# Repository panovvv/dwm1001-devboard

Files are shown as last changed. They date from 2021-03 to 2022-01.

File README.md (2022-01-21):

# DWM1001 Development board
Breakout board for DWM1001 UWB module.

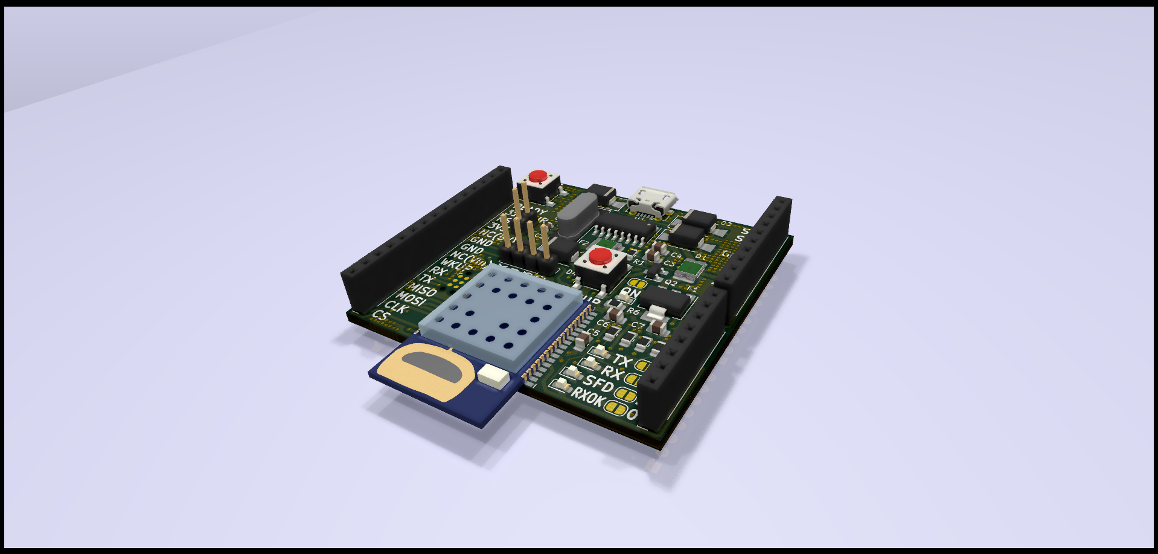
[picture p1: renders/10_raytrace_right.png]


[> Demo video here <](https://www.youtube.com/watch?v=SorOhWdywFg)

Intended for easy exploration:
* Modular thanks to compatibility with Arduino Uno shield footprint.
* Modules can be battery-powered using a simple DIY battery shield.
* Open access to all GPIOs.

## Files and folders:

* `dwm1001-devboard.***`- KiCAD schematics and PCB files.
* `schematic.pdf` - full schematic sheet rendered in PDF.
* `bom.csv` - Bill of Materials, semicolon-separated.
* `paper_footprint_test.pdf` - this is my usual practice when designing and ordering PCBs:
before even designing the board layout, I plot the empty board with all footprints in it to PDF
(1:1 scale), print it on a sheet of paper and do a "test fit" for every component. This helps 
to find footprint inconsistencies early on.
* `gerber/` - Generated according to
[this document](https://support.jlcpcb.com/article/102-kicad-515---generating-gerber-and-drill-files).
To order the PCB made, just zip up all files in `gerber/` folder and send to fab.
* `renders/` - 3D renders and STL of the board with all components populated.
* `SMD_Polyfuse_1812.stp` - model for PTC fuse in 1812 package, courtesy of 
  [Joan The Spark](https://forum.kicad.info/u/Joan_Sparky) distributed under GNU General Public License v2.0. 
  Source: [Kicad forum](https://forum.kicad.info/t/polyfuse-3d-models/6859), [direct link](https://kicad-info.s3-us-west-2.amazonaws.com/original/2X/6/6d10c55baa8ffbd4a3f9c269ba751e2fab07bd70.stp)

## BOM

|Designator|Package |Quantity|Value |
|---|---|---|---|
|F2,F1 |1812 (4532 Metric) |2 |0.5A PTC fuse |
|C2,C1 |0603 (1608 Metric) |2 |22pF ceramic capacitor |
|Y1 |HC49-SD SMD |1 |12MHz crystal oscillator |
|U1 |SOIC-16 |1 |CH340G |
|J1 |Micro USB Type B, SMD |1 |Micro USB B connector, female |
|SW1, SW2  |SPST Pushbutton 6x6mm, SMD |2 |WKUP, RST buttons |
|U3 |SOT-223-3 |1 |AMS1117-3.3 3.3V voltage regulator |
|U2 |DecaWave DWM1001 |1 |DWM1001 |
|R1 |0805 (2012 Metric) |1 |100kΩ resistor |
|Q2,Q1 |SuperSOT-3 |2 |FDN430P P-MOSFET |
|JP1 |2.54mm pitch Male Pin Header 1x02 Vertical  |1 |3.3V Current probe jumper |
|J7 |2.54mm pitch Female Pin Header 1x10 Vertical|1 |Arduino Stackable type if possible |
|J6 |2.54mm pitch Female Pin Header 1x08 Vertical|1 |Arduino Stackable type if possible |
|J4 |2.54mm pitch Female Pin Header 1x15 Vertical|1 |Arduino Stackable type if possible |
|J5 |Tag-Connect TC2030-IDC |1 |Tag-Connect TC2030 SWD |
|J2 |2.54mm pitch Male Pin Header 1x04 Vertical  |1 |SWD Pin Header Male |
|D4 |SMA or SMB Diode |1 |SMBJ3.3A Transient voltage suppressor|
|D1 - D3 |SMA or SMB Diode |3 |SMBJ5.0A Transient voltage suppressor|
|C5,C3 |0805 (2012 Metric) |2 |100nF ceramic capacitor |
|C7,C6,C4  |0805 (2012 Metric) |3 |10µF ceramic capacitor |
|D9 |0603 (1608 Metric) |1 |Green LED |
|D8,D6 |0603 (1608 Metric) |2 |Red LED |
|D7,D5 |0603 (1608 Metric) |2 |Blue LED |
|R6 |0805 (2012 Metric) |1 |47Ω resistor, for green LED @ 3.3V |
|R5,R3 |0805 (2012 Metric) |2 |75Ω resistor, for red LED @ 3.3V |
|R4,R2 |0805 (2012 Metric) |2 |15Ω resistor, for blue LED @ 3.3V |

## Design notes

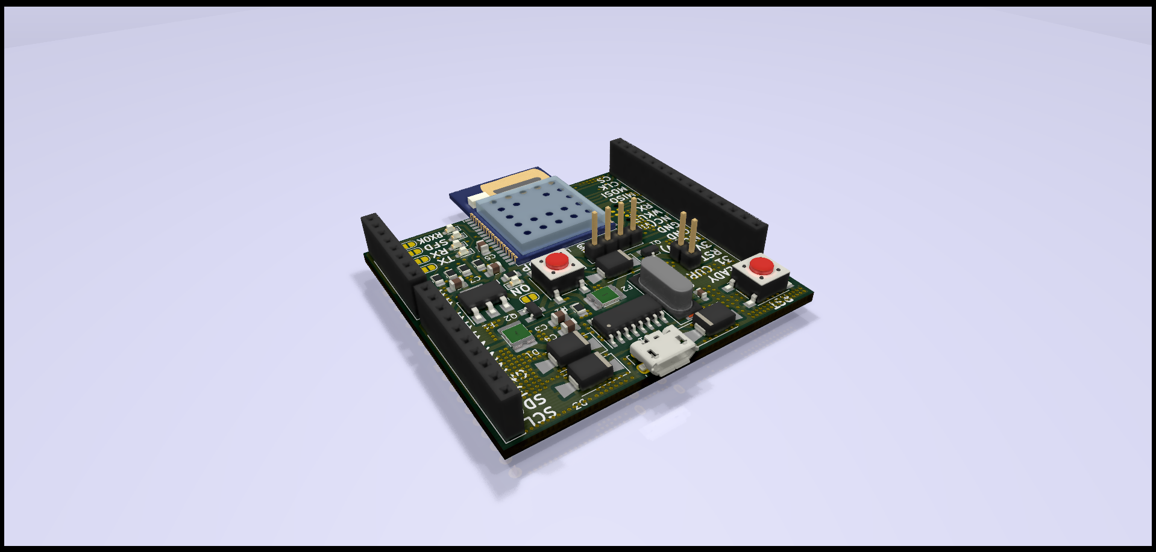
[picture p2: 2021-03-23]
renders/12_raytrace_right_180deg.png

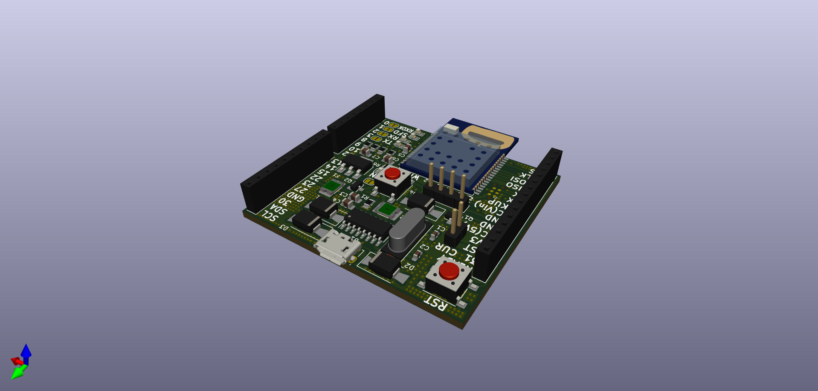
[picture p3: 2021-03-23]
renders/05_no_raytrace_left_180deg.png

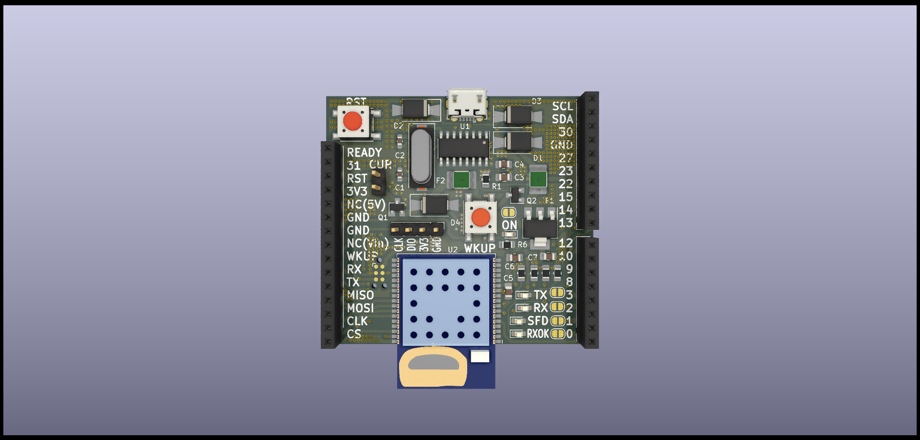
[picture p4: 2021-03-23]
renders/07_raytrace_front.png

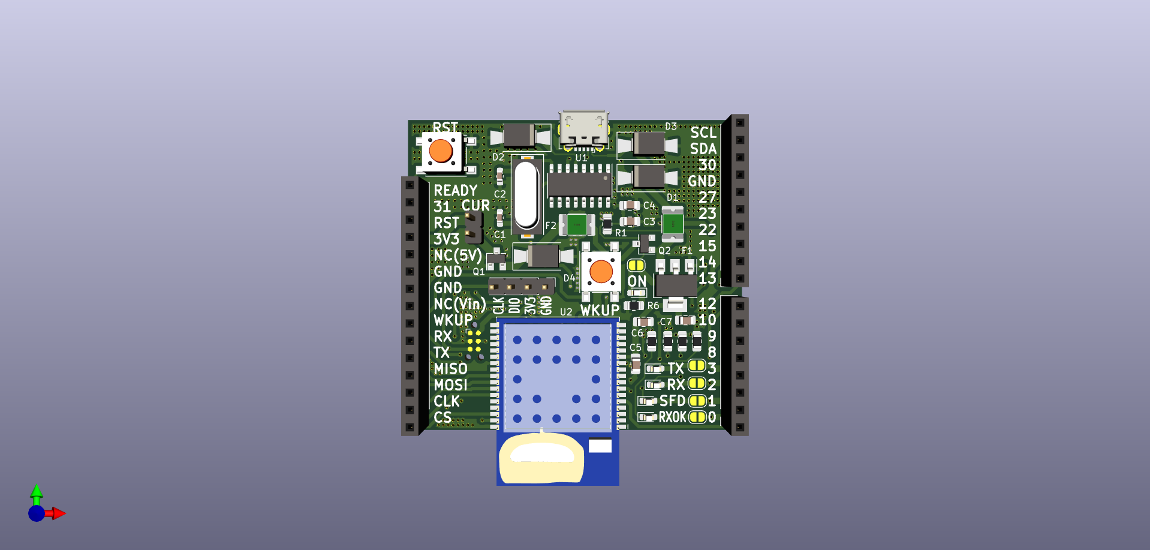
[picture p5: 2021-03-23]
renders/01_no_raytrace_front.png

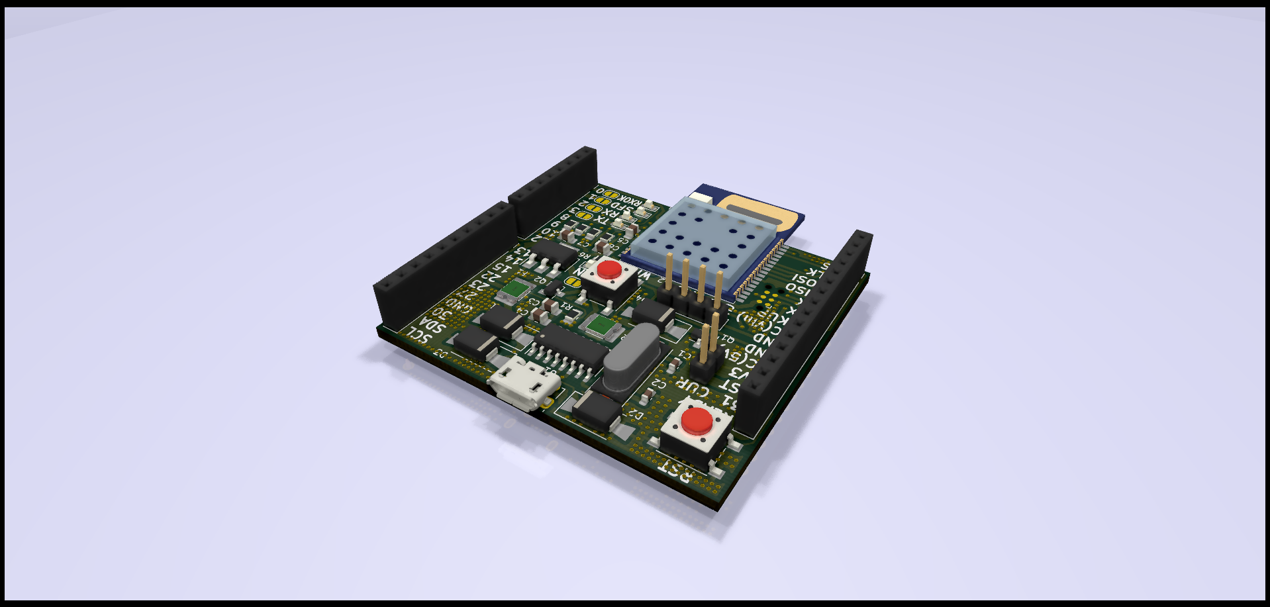
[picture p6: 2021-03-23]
renders/11_raytrace_left_180deg.png

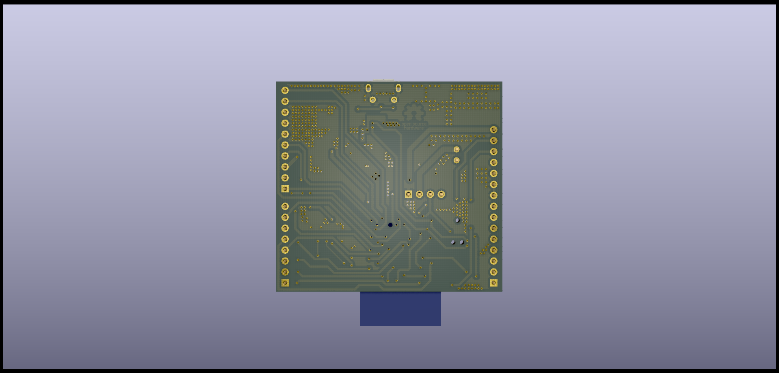
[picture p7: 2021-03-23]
renders/08_raytrace_back.png

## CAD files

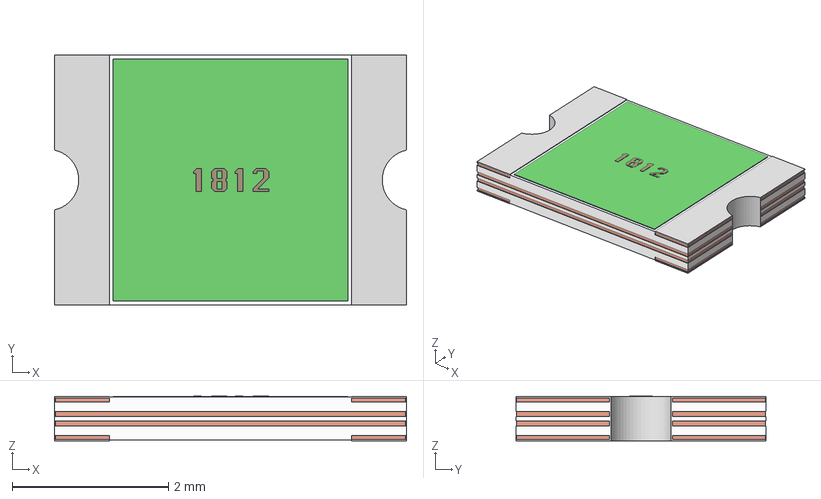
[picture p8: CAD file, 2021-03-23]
SMD_Polyfuse_1812.stp
4.50 x 3.20 x 0.575 mm

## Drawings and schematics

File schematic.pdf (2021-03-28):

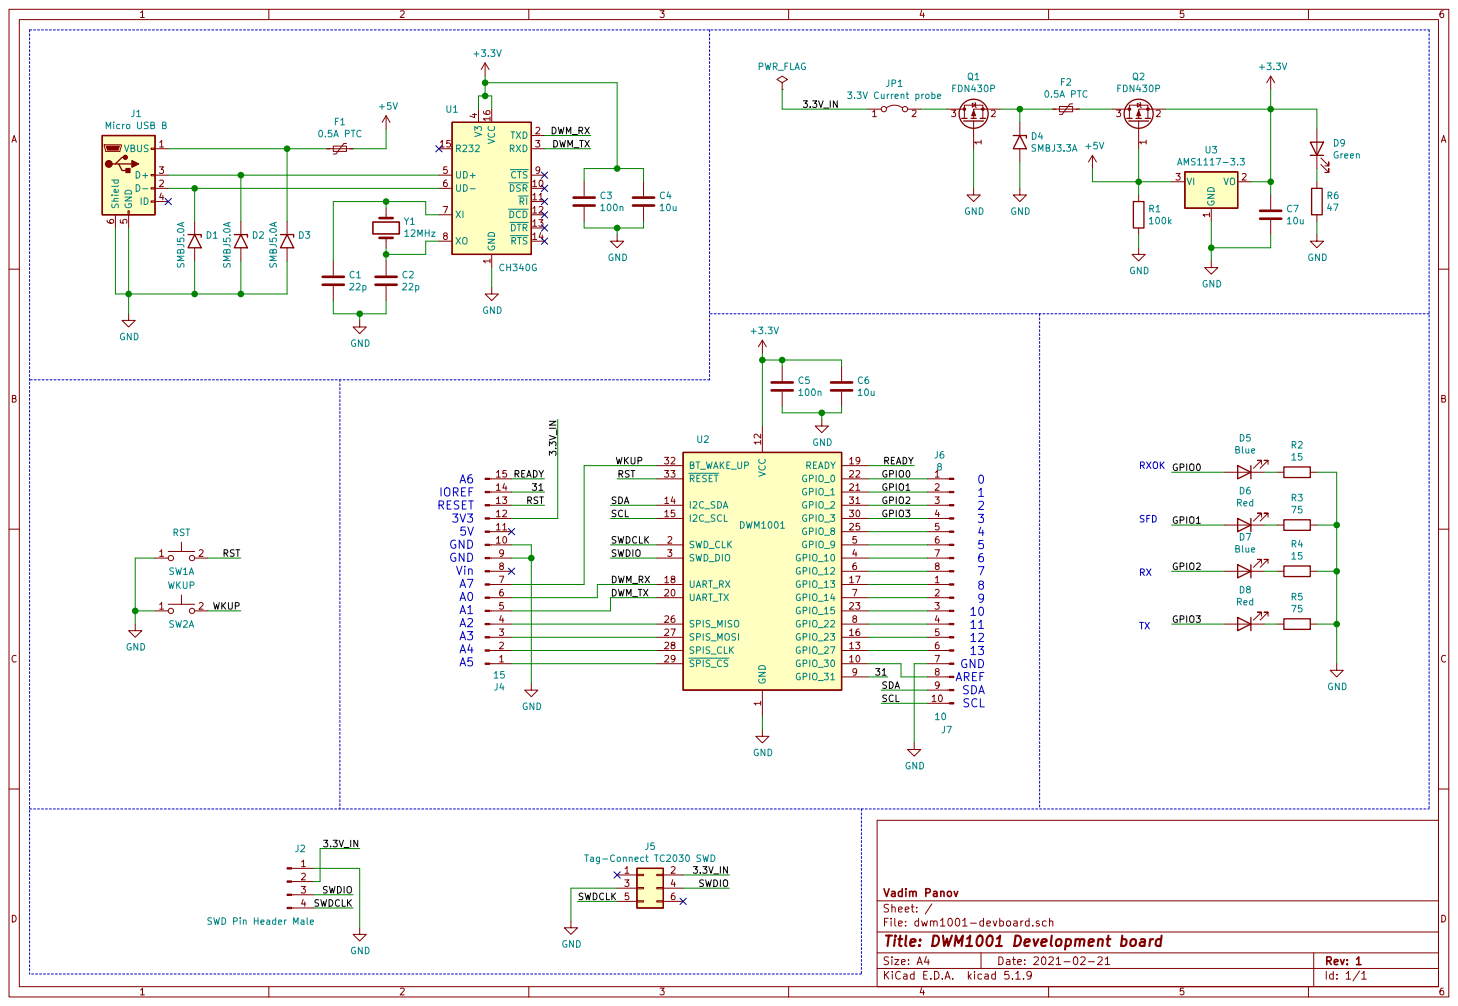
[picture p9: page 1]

4 UD+ 5 UD- 6 XI 7 XO 8 CTS 9 U1 CH340G GND

1 DSR 10 RI 11 DCD 12 DTR 13 RTS 14 R232 15 VCC 16 TXD 2 RXD 3 V3

File: dwm1001-devboard.sch Sheet: / Vadim Panov GND

J2 SWD Pin Header Male

Id: 1/1 Title: DWM1001 Development board

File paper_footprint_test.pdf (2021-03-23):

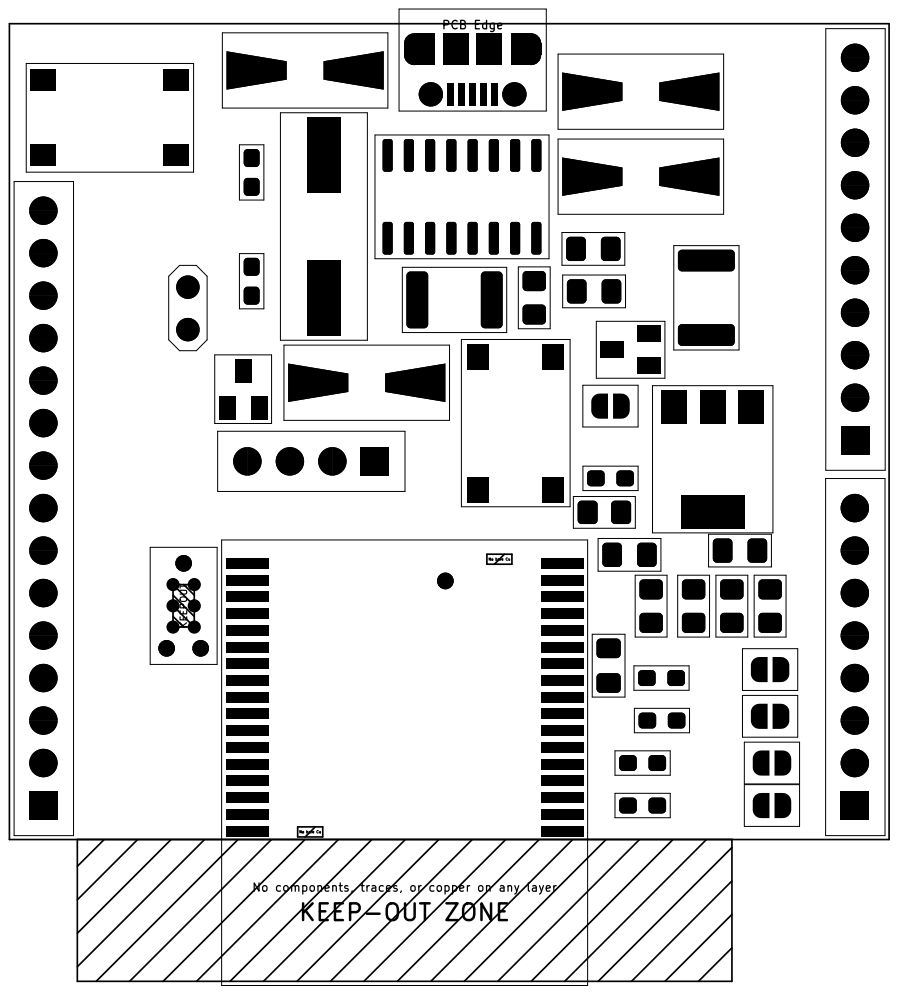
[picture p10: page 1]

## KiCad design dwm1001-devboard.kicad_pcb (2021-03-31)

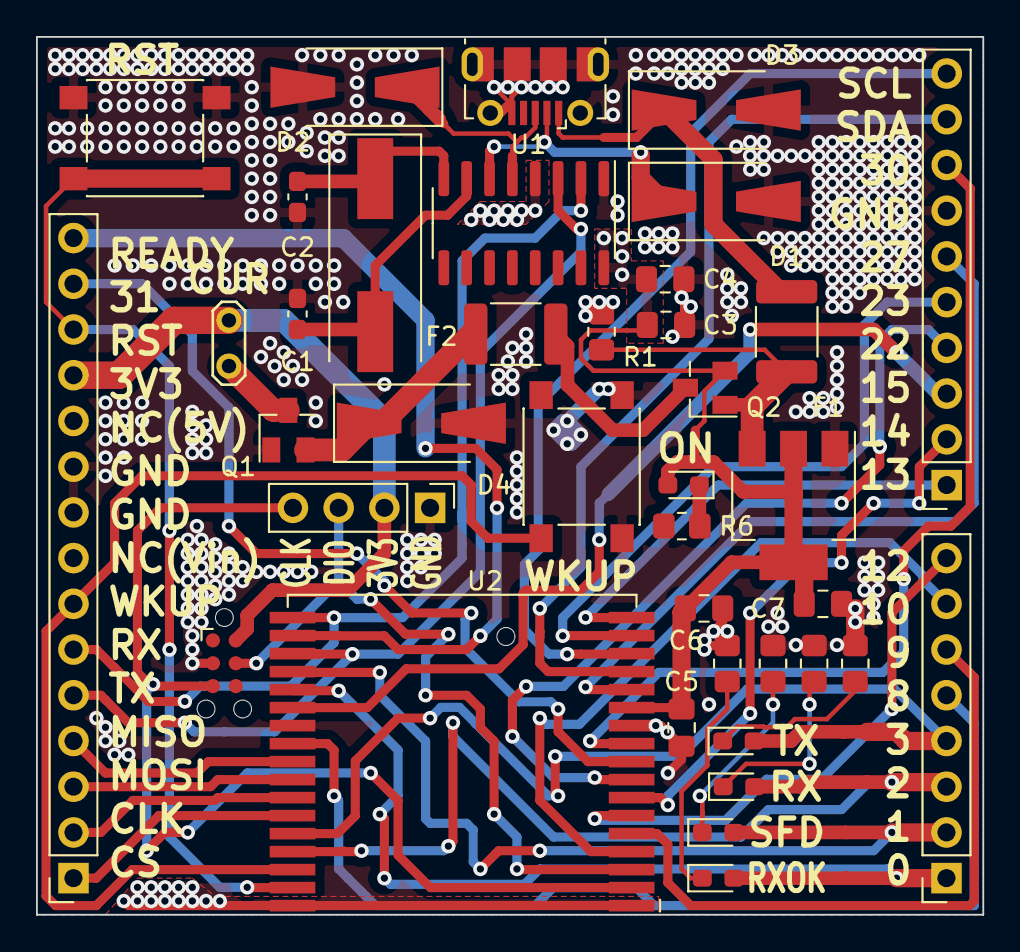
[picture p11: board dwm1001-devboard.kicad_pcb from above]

Board: 2 copper layers, 52.6 x 48.8 mm, 39 parts (0 on the bottom side), 46 nets.

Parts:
C1, C2: 22p; C_0603_1608Metric_Pad1.08x0.95mm_HandSolder
C3, C5: 100n; C_0805_2012Metric_Pad1.18x1.45mm_HandSolder
C4, C6, C7: 10u; C_0805_2012Metric_Pad1.18x1.45mm_HandSolder
D1, D2, D3: SMBJ5.0A; D_SMA-SMB_Universal_Handsoldering
D4: SMBJ3.3A; D_SMA-SMB_Universal_Handsoldering
D5, D7: Blue; LED_0603_1608Metric_Pad1.05x0.95mm_HandSolder
D6, D8: Red; LED_0603_1608Metric_Pad1.05x0.95mm_HandSolder
D9: Green; LED_0603_1608Metric_Pad1.05x0.95mm_HandSolder
F1, F2: 0.5A PTC; Fuse_1812_4532Metric_Pad1.30x3.40mm_HandSolder
J1: Micro USB B; USB_Micro-B_Molex-105017-0001
J2: SWD Pin Header Male; PinHeader_1x04_P2.54mm_Vertical
J4: 15; PinSocket_1x15_P2.54mm_Vertical
J5: Tag-Connect TC2030 SWD; Tag-Connect_TC2030-IDC-NL_2x03_P1.27mm_Vertical
J6: 8; PinSocket_1x08_P2.54mm_Vertical
J7: 10; PinSocket_1x10_P2.54mm_Vertical
JP1: 3.3V Current probe; TestPoint_2Pads_Pitch2.54mm_Drill0.8mm
Q1, Q2: FDN430P; SuperSOT-3
R1: 100k; R_0805_2012Metric_Pad1.20x1.40mm_HandSolder
R2, R4: 15; R_0805_2012Metric_Pad1.20x1.40mm_HandSolder
R3, R5: 75; R_0805_2012Metric_Pad1.20x1.40mm_HandSolder
R6: 47; R_0805_2012Metric_Pad1.20x1.40mm_HandSolder
SW1: RST; SW_Push_1P1T_NO_6x6mm_H9.5mm
SW2: WKUP; SW_Push_1P1T_NO_6x6mm_H9.5mm
U1: CH340G; SOIC-16_3.9x9.9mm_P1.27mm
U2: DWM1001; DecaWave_DWM1001
U3: AMS1117-3.3; SOT-223-3_TabPin2
Y1: 12MHz; Crystal_SMD_HC49-SD

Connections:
+3V3: C3.1, C4.1, C5.1, C6.1, C7.1, D9.2, Q2.2, U1.4, U1.16, U2.12, U3.2
+5V: F1.1, Q2.1, R1.1, U3.3
/3.3V_IN: J2.2, J4.12, J5.2, JP1.1
/31: J4.14, U2.9
/DWM_RX: J4.6, U1.2, U2.18
/DWM_TX: J4.5, U1.3, U2.20
/GPIO0: D5.2, J6.1, U2.22
/GPIO1: D6.2, J6.2, U2.21
/GPIO2: D7.2, J6.3, U2.31
/GPIO3: D8.2, J6.4, U2.30
/READY: J4.15, U2.19
/RST: J4.13, SW1.2, U2.33
/SCL: J7.10, U2.15
/SDA: J7.9, U2.14
/SWDCLK: J2.4, J5.5, U2.2
/SWDIO: J2.3, J5.4, U2.3
/WKUP: J4.7, SW2.2, U2.32
GND: C1.2, C2.2, C3.2, C4.2, C5.2, C6.2, C7.2, D1.2, D2.2, D3.2, D4.2, J1.5, J1.6, J2.1, J4.9, J4.10, J5.3, J7.7, Q1.1, R1.2, R2.1, R3.1, R4.1, R5.1, R6.2, SW1.1, SW2.1, U1.1, U2.1, U2.11, U2.24, U2.34, U3.1
unnamed: C1.1, U1.7, Y1.2
unnamed: C2.1, U1.8, Y1.1
unnamed: D1.1, J1.2, U1.6
unnamed: D2.1, J1.3, U1.5
unnamed: D3.1, F1.2, J1.1
unnamed: D4.1, F2.2, Q1.2
unnamed: D5.1, R2.2
unnamed: D6.1, R3.2
unnamed: D7.1, R4.2
unnamed: D8.1, R5.2
unnamed: D9.1, R6.1
unnamed: F2.1, Q2.3
unnamed: J4.1, U2.29
unnamed: J4.2, U2.28
unnamed: J4.3, U2.27
unnamed: J4.4, U2.26
unnamed: J6.5, U2.25
unnamed: J6.6, U2.5
unnamed: J6.7, U2.4
unnamed: J6.8, U2.6
unnamed: J7.1, U2.17
unnamed: J7.2, U2.7
unnamed: J7.3, U2.23
unnamed: J7.4, U2.8
unnamed: J7.5, U2.16
unnamed: J7.6, U2.13
unnamed: J7.8, U2.10
unnamed: JP1.2, Q1.3

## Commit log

2021-03-23 first implementation
    [SMD_Polyfuse_1812.stp, bom.csv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]
2021-03-28 get rid of solder jumpers
    [dwm1001-devboard-B_Cu.gbr, dwm1001-devboard-B_Mask.gbr, dwm1001-devboard-B_SilkS.gbr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]
2021-03-31 remove solder jumpers, add dimensions to the PCB. First batch of PCBs ordered
    [dwm1001-devboard.kicad_pcb]
2021-05-11 declutter BOM file
    [bom.csv]
2021-09-27 small bom fix
    [bom.csv]

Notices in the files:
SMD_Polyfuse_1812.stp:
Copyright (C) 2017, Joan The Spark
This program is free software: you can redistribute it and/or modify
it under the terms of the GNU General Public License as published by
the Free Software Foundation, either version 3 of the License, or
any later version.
